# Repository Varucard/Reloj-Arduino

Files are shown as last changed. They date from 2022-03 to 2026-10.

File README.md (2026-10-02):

# Reloj Arduino



Reloj despertador casero hecho con Arduino. Muestra la hora, la fecha, la temperatura y la humedad ambiente, y tiene una alarma que se apaga **sacudiendo el reloj**.

## Funcionalidades

- Hora y fecha desde un módulo RTC DS1302, que mantiene la hora aunque se corte la alimentación.
- Temperatura y humedad con un sensor DHT11, actualizadas cada 6 segundos.
- Alarma con melodía en un buzzer, guardada en EEPROM, que se conserva al reiniciar.
- La alarma se apaga con 6 sacudidas (sensor de inclinación SW-520D), con el botón ALARM o sola a los 5 minutos.
- Ajuste de fecha, hora y alarma desde los botones, sin necesidad de reprogramar.
- Luz de fondo de la pantalla que se puede prender y apagar.

## Hardware

| Componente | Detalle |
|---|---|
| Placa | Arduino Uno o Arduino Pro Mini (ATmega328P) |
| Pantalla | LCD 16x2 con adaptador I2C (PCF8574, dirección `0x27`) |
| Reloj | Módulo RTC DS1302 |
| Sensor ambiente | DHT11 |
| Sensor de movimiento | SW-520D (inclinación) |
| Sonido | Buzzer pasivo |
| Entradas | 5 pulsadores |

### Conexiones

| Pin Arduino | Conectado a |
|---|---|
| A4 / A5 | LCD I2C (SDA / SCL) |
| 4 | Botón LOOK |
| 5 | DHT11 (datos) |
| 6 / 7 / 8 | DS1302 (CLK / DAT / RST) |
| 9 | Botón SET |
| 10 | Botón UP |
| 11 | Botón DOWN |
| 12 | Botón ALARM |
| 13 | Buzzer |
| A3 | SW-520D |

Los botones van entre el pin y GND; se usan las resistencias pull-up internas. Los esquemas completos están en [`hardware/esquemas`](hardware/esquemas) (PNG y archivos editables de [Fritzing](https://fritzing.org/)).

## Uso

| Botón | Funcionamiento normal | En modo ajuste |
|---|---|---|
| **SET** | Entra al modo ajuste | Pasa al siguiente campo; en el último, guarda |
| **UP** | — | Aumenta el valor |
| **DOWN** | Prende o apaga la luz de fondo | Disminuye el valor |
| **ALARM** | Arma o desarma la alarma; si está sonando, la silencia | — |
| **LOOK** | Muestra un segundo la hora de la alarma y su estado | — |

El modo ajuste recorre, en orden: hora → minutos → día → mes → año → hora de alarma → minutos de alarma. El RTC solo se reescribe si se modificó la fecha o la hora (los segundos se ponen en 00); si solo se cambia la alarma, la hora del reloj no se toca.

```
Pantalla principal   Info de alarma       Ajuste fecha/hora    Ajuste alarma
+----------------+   +----------------+   +----------------+   +----------------+
|HH:MM DD/MM/YYYY|   |HH:MM:SS| HH:MM |   |    >HH : MM    |   |SET  ALARM TIME |
|Temp:27c Hum:74%|   |DD/MM/YYYY| ON  |   | DD / MM / YYYY |   |    >HH : MM    |
+----------------+   +----------------+   +----------------+   +----------------+
```

## Compilación

### Librerías

| Librería | Uso | Instalación |
|---|---|---|
| [DHTlib](https://github.com/RobTillaart/DHTlib) | `dht.h` – sensor DHT11 | Gestor de librerías del IDE |
| [New LiquidCrystal](https://github.com/fmalpartida/New-LiquidCrystal) | `LCD.h`, `LiquidCrystal_I2C.h` – pantalla | Agregar el `.zip` desde GitHub |
| [virtuabotixRTC](https://github.com/chrisfryer78/ArduinoRTClibrary) | `virtuabotixRTC.h` – DS1302 | [`libraries/virtuabotixRTC.zip`](libraries) |

> **Importante:** New LiquidCrystal reemplaza a la librería `LiquidCrystal_I2C` de Frank de Brabander. Si tenés esa otra instalada, desinstalala o renombrala, porque si no el sketch no compila.

### Arduino IDE

1. Instalar las librerías (*Programa → Incluir librería → Añadir biblioteca .ZIP*).
2. Abrir `firmware/RelojArduino/RelojArduino.ino`.
3. Elegir la placa (Uno o Pro Mini) y subir.

### arduino-cli

```bash
arduino-cli core install arduino:avr
arduino-cli lib install DHTlib
arduino-cli config set library.enable_unsafe_install true
arduino-cli lib install --git-url https://github.com/fmalpartida/New-LiquidCrystal.git
arduino-cli lib install --zip-path libraries/virtuabotixRTC.zip

arduino-cli compile firmware/RelojArduino                               # Uno (por defecto)
arduino-cli compile -b arduino:avr:pro firmware/RelojArduino            # Pro Mini
arduino-cli upload -p /dev/ttyUSB0 firmware/RelojArduino
```

Cada push compila el firmware automáticamente para ambas placas con GitHub Actions.

## Estructura del repositorio

```
firmware/RelojArduino/   Sketch principal
hardware/esquemas/       Diagramas de conexión (PNG y Fritzing .fzz)
libraries/               Copias de las librerías usadas
docs/datasheets/         Hojas de datos de los componentes
docs/referencias/        Proyectos de Instructables en los que se basa este reloj
```

## Créditos

Basado en estos proyectos de Instructables, adaptados y extendidos:

- [Arduino Digital Clock With Alarm Function (custom PCB)](https://www.instructables.com/Arduino-Digital-Clock-With-Alarm-Function-custom-P/)
- [Arduino Digital Clock Thermometer (3D Printer Files)](https://www.instructables.com/Arduino-Digital-Clock-Thermometer-3D-Printer-Files/)

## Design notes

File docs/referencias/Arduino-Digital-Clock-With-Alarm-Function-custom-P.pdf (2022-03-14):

instructables

## Arduino Digital Clock With Alarm Function (custom PCB)

by Ardumotive_com

In this DIY guide I will show you how to make your own digital clock this alarm function.

In this project I decided to make my own PCB that is based on Arduino UNO microcontroller -Atmega328p.

Bellow you will find the electronic schematic with PCB layout so you can easily produce it.

By pressing the buttons you will be able to set time/date/alarm and alarm state (on/off).

The alarm can be turned off by pressing the alarm button or by shacking the box.

Updates and more can be found here: http://www.ardumotive.com/arduino-digital-clock-with-alarm-functionen.html

Let's get started.

https://www.youtube.com/embed/auJJn6xp2Go

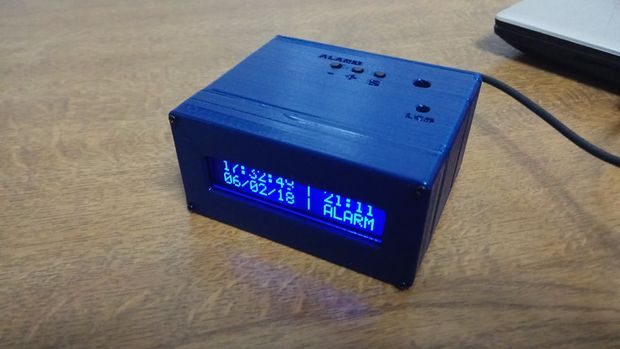
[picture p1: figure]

Arduino Digital Clock With Alarm Function (custom PCB): Page 1

### Step 1: What You Will Need - Hardware

For this project you will need:

Our custom PCB circuit
High Contrast 16x2 Character LCD (Raystar RC1602B-LLG-JWVE) Atmega328 (with Arduino UNO bootloader)
DS1307 Real Time Clock
Tilt Sensor
28 dip socket & 8 dip socket
16 MHz crystal oscillator
32.768 MHz crystal oscillator 2x22 pF capacitors
3x10 kOhm resistor
Trimmer 20kOhm
Buzzer
Coin Cell Battery Holder
screw terminal 2P 2.54mm
Pin Header 1x5 Female 2.54mm Mini Push Button Switch - Tall

You will also need a TTL to USB module or an Arduino UNO board for the programming procedure.

For power you will need a 5V-1A power adapter or you can use a usb cable as I did.

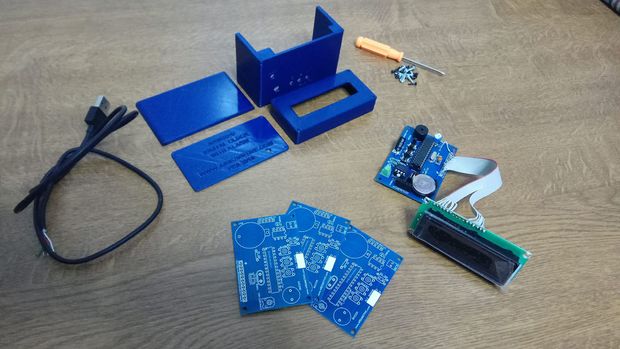
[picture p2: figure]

### Step 2: The Circuit at EasyEDA, the Free Online Circuit Design Platform

Enter here to see and make any changes to the above circuit.

Arduino Digital Clock With Alarm Function (custom PCB): Page 2

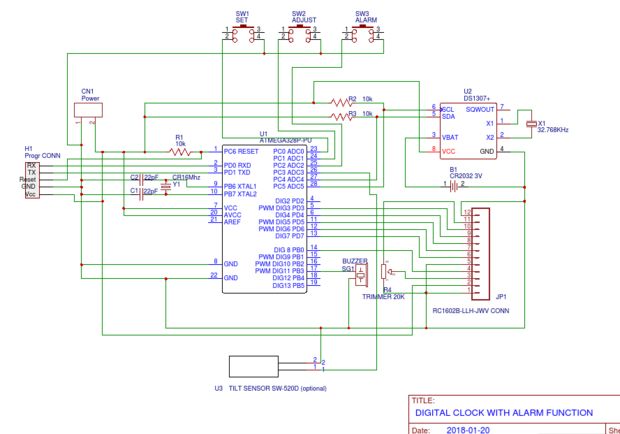
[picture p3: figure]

http://www.instructables…

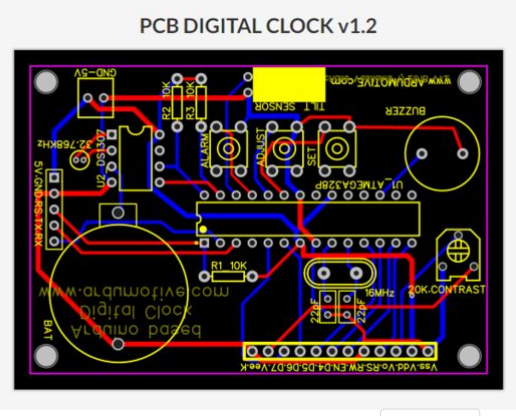
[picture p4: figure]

Download

### Step 3: The Code

How to program it:

Connect your circuit with TTL to USB module with 5 cables to the programming header.

The pins RX and TX must be cross-connected.

NOTE: If you are using the Arduino UNO board make sure to remove the ATmega328 IC from it first and connect the headers RX to RX and TX to TX pins of the board. The RS pin must be connected to Arduino UNO reset pin.

Download the code from here and open it with Arduino IDE. Inside you will also find the library file.

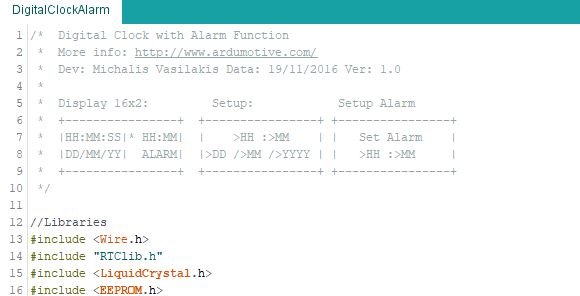
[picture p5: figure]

http://www.instructables…

Download

Arduino Digital Clock With Alarm Function (custom PCB): Page 3

### Step 4: JLCPCB - Make Your Own Circuit Boad From 2$!

Enter here to produce your PCB board!

Use JLCPCB for $2 PCB Fabrication & 2-day Build Time, the quality is really good, check the below photo of our pcb board.

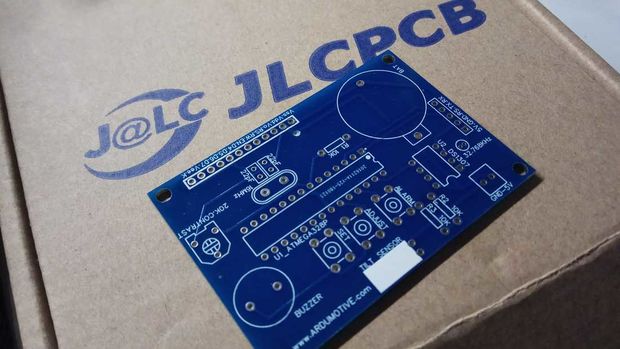
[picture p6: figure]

### Step 5: 3D Parts

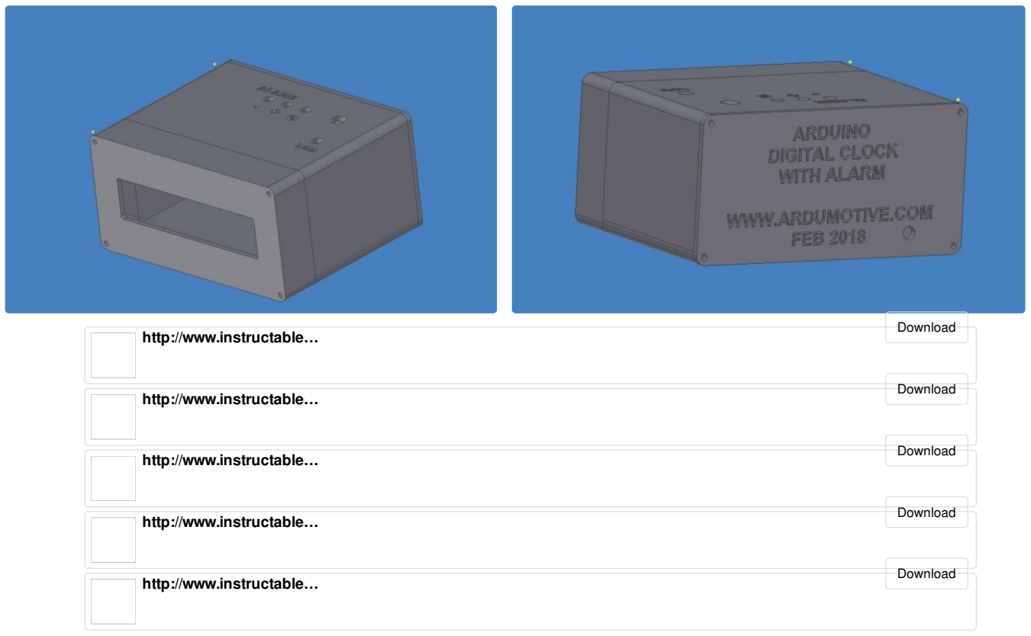
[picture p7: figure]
http://www.instructables…; Download

Arduino Digital Clock With Alarm Function (custom PCB): Page 4

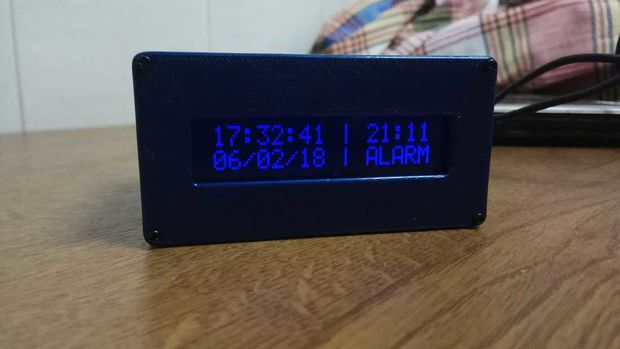
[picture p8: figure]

Thank you very much for your comment! I really appreciate it!
* Part list updated
* About video, I will try to make a better one next time and I will follow your advice
* I understand what you are telling me about easyeda and I will agree with you
* About JLCPCB, I will disagree with you, the quality of my PCBs is very good
* About connections, PCB layout has labels for all connection parts, plus CN1 (power).

With regard to the PCB, you and I are actually in full agreement. Your PCB quality is good because your layout work and attention to design rules were very good. I think you did a good job on the PCB.

I can't say the same for nearly every other project I've seen from JLCPCB.

But yours are good!

I'm not a fan of EasyEDA or JLCPCB because many of the projects that end up on Instructables are junk. But I think this project is a bit better than it's peers. I like this one and think it looks totally cool. The author has included information on almost everything you would need to make the project including 3D print files for the case. So you don't really need to buy the PCB from JLCPCB. You could even wire this up on perfboard if you wanted to spend the time on it.

For some reason EasyEDA doesn't produce clean schematics. Most of the projects using it have lines running through text or components, text too close, component outlines too small for the text within them... stuff like that. The schematic for this project has some of those, but it appears the author did spend a good bit of time getting the drawing to look right. I'm not sure if you can download the schematic from the EasyEDA site referenced by the author and use it with a better schematic editor, but at least there's a decent schematic to go with this project.

I have the same issue with EasyEDA PCB layouts. Most projects featuring it look terrible. Wrong part outlines, extremely poor layout, silkscreen text run over pads, silkscreen text run over mounting holes, and worse... silkscreen text under component bodies. But the author of this project has taken the time to do a decent layout. All parts fit and are in their proper place. One of the few I've seen from JLCPCB that are even close to usable.

The author includes a parts list, but I would have liked more complete specifications or a link on the

### Step 6: Well Done!

I hope you liked this, let me know in the comments!!!

Arduino Digital Clock With Alarm Function (custom PCB): Page 5

Instructables site that shows where they can be ordered from. This is done in the authors
EasyEDA site, so if you need more information on the parts you'll need to visit the EasyEDA site. It just would have been nice to see that on the Instructables site.

A couple of omissions to be aware of:

The push button switches aren't included in the parts list. You can see them in the picture but for the case to go together properly, the exact switch the author used needs to be ordered.

The LCD display isn't specified. This might be one of those Arduino parts that everybody has and everybody knows what it is, but I think it would be better to include a description and link to the display used.

The USB cable shown isn't specified. It would be great if a part number or link were provided for this.

From an assembly standpoint:

It's not clear how the LCD is wired into the main PCB. A little more information on that would be helpful for those who haven't done it before. Including this on a separate schematic page or illustration diagram would have been great.

It's not clear what the USB cable with the bare leads is for. A little more information on that would be helpful. I'm assuming that cable is used to power the clock with 5V via connector CN1. But it's not clear and available documentation is silent.

There is mention that a TTL to USB module is needed but that's not shown or described. A little more information on that module and how to connect it would be helpful for those who haven't programmed an Atmega chip in a dedicated PCB before. The less additional research the reader has to do, the more time they can spend just building the project.

The video is nice to have, but half of it is the usual advertisement for JLCPCB. The author could have used that time to include additional information on how to build and program the project. But least every single step in this Instructable doesn't come with the usual appeal to "Buy the PCB! Buy the PCB!" I hate that.

Minus a few missing parts, this is an project that can be made using the information the author has provided. It looks cool and you can build it however you want.

Arduino Digital Clock With Alarm Function (custom PCB): Page 6

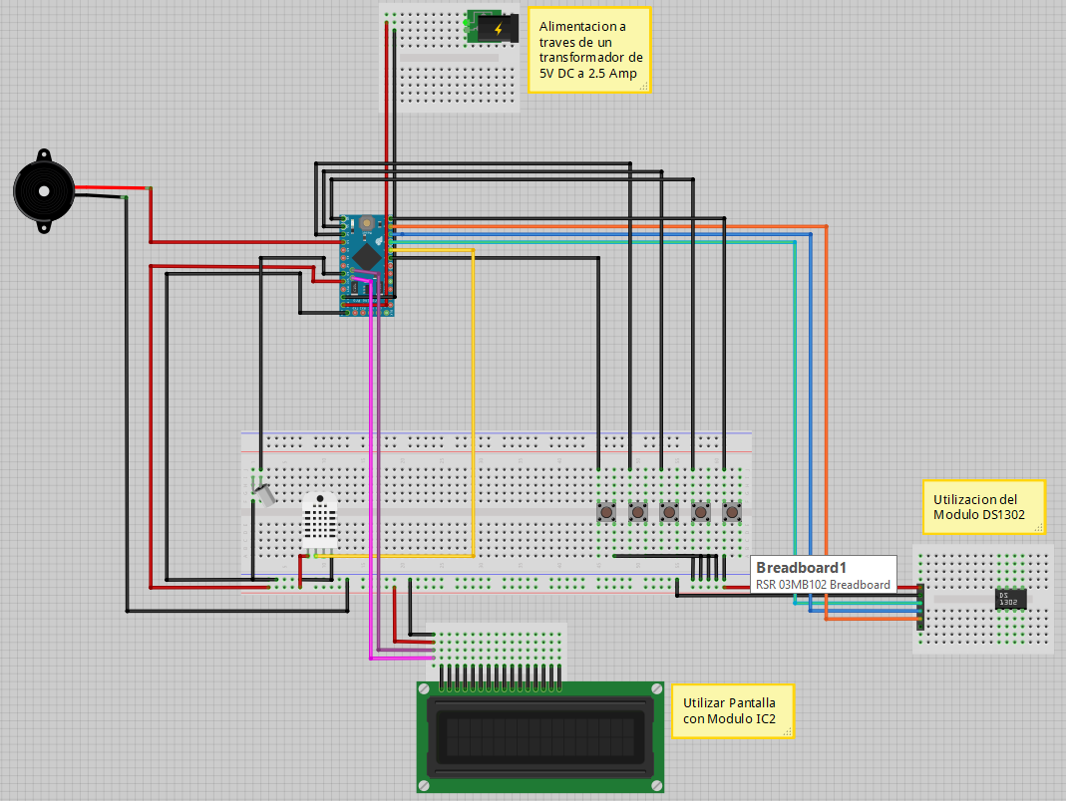
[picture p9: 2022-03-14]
hardware/esquemas/reloj-arduino-pro-mini.png

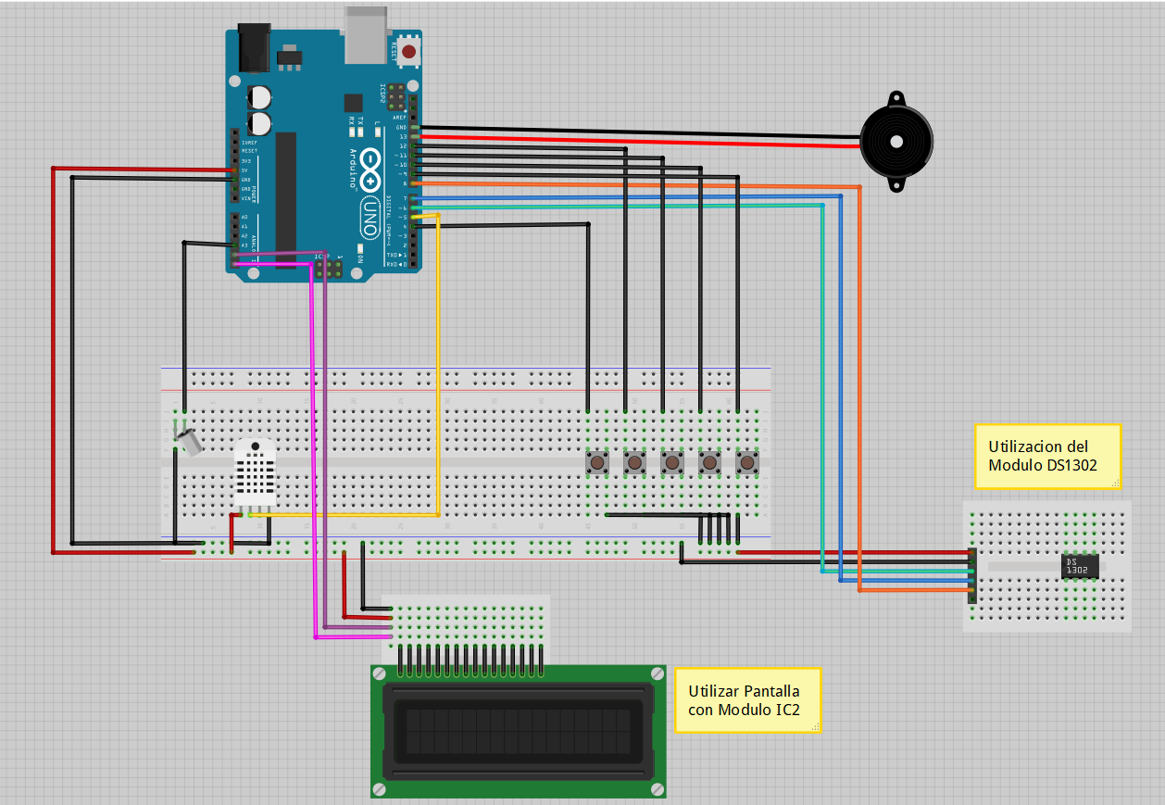
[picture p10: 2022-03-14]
hardware/esquemas/reloj-arduino-uno.png

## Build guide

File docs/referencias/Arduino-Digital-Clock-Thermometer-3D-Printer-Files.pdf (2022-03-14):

http://www.instructables.com/id/Arduino-Digital-Clock-Thermometer-3D-Printer-Files/technology (http://www.instructables.com/tag/type-id/category-technology/) workshop (http://www.instructables.com/tag/type-id/category-workshop/) craft (http://www.instructables.com/tag/type-id/category-craft/) home (http://www.instructables.com/tag/type-id/category-home/) food (http://www.instructables.com/tag/type-id/category-food/) play (http://www.instructables.com/tag/type-id/category-play/) outside (http://www.instructables.com/tag/type-id/category-outside/) costumes (http://www.instructables.com/tag/type-id/category-costumes/)

# Arduino Digital Clock & Thermometer (+3D Printer files)

by Ardumotive_com (http://www.instructables.com/member/Ardumotive_com/?utm_source=pdf&utm_campaign=title) on December 4, 2016

Table of Contents

## Intro: Arduino Digital Clock & Thermometer (+3D Printer files)

In this "how to" guide i will show you how to make your own digital clock-thermometer with the Arduino Pro mini board. (yes, you can use any other Arduino boad) .

You will be able to change the current date and time with Set-Up-Down buttons. The "down" button can also be used to turn on/off the screen backlight. The time and date values are stored in memory of the RTC.

The Temperature and humidity values updated every 5 seconds. We will use the DHT-21 sensor, but you can also use the DHT-11 and DHT-22 versions (you will need to make some changes in the code below).

Visit this page for further updates: http://www.ardumotive.com/digitalclockther-en.html

Watch the presentation video below.

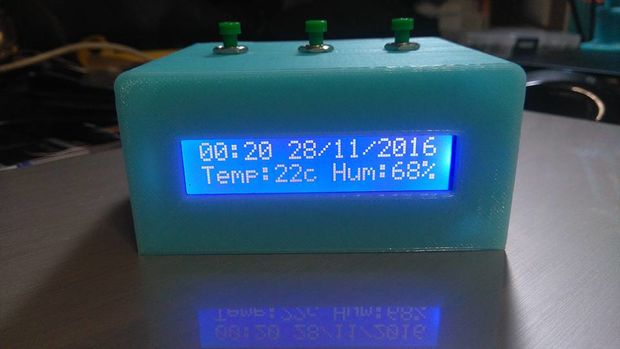
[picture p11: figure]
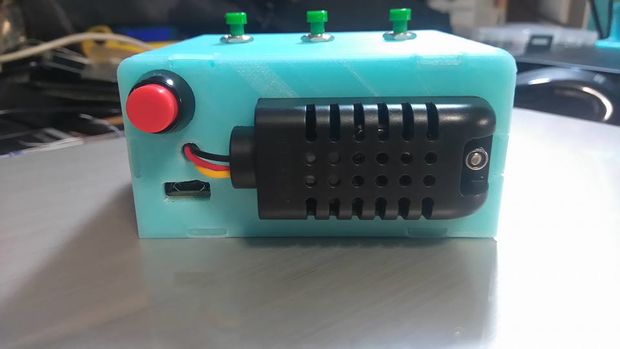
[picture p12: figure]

## Step 1: What you will need - Hardware

For this project you will need:

Arduino Pro Mini (5v version)
I2C LCD 16x2
DHT-21
RTC DS1307 (module with cell battery)
3 push buttons
1 on/off button

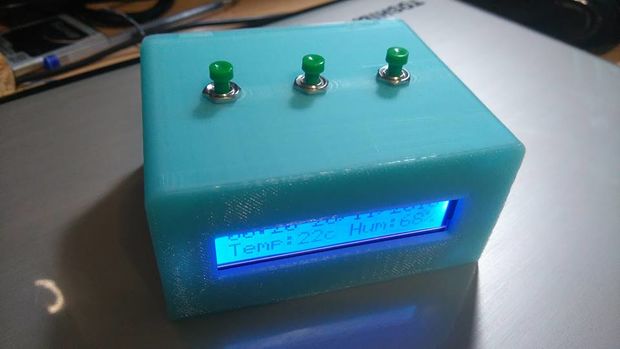
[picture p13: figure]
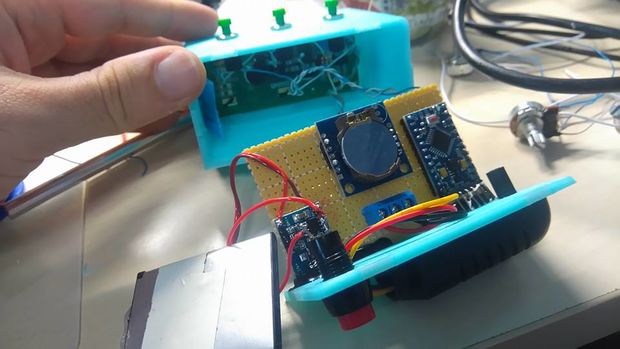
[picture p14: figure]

If you want you can use a rechargeable battery and a charging circuit as I did. (I used an old 950mAh mobile phone battery)

Or you can simply use one DC jack and one 5V power adapter to power it up!

## Step 2: The circuit

The circuit is really simple.

The i2c lcd and RTC module must be connected to the Arduino SDA and SCL pins. If you are using the Arduino uno or Arduino Pro Mini (or another board based in atMega328p micro controller), use the I2C interface at A4 (SDA) and A5(SCL) pins.

I2C LCD 16x2:
Vcc to power source (max 5V!)
GND to GNDSDA to pin A4
SCL to pin A5

RTC DS1307 module:
Vcc to power source (max 5V!) GND to GND

SDA to pin A4
SCL to pin A5

DHT-21:
Red cable to power source (max 5V!) Black cable to GND
Yellow cable to pin 5

Push buttons:

Set button to pin 8
Up button to pin 9
Down button to pin 10
The second pin of all buttons must be connected to ground (GND)

## Step 3: The code

Download the code from here and open it with Arduino IDE. Inside you will also find all necessary libraries.

If have any difficulties with the i2c LCD complete this tutorial. (http://www.ardumotive.com/i2clcden.html)

File Downloads

Clock_and_Thermometer_I2CLCD_DHT21.zip (http://www.instructables.comhttps://cdn.instructables.com/ORIG/F0Z/46G8/IW6PQNXL/F0Z46G8IW6PQNXL.zip) (6 MB)
[NOTE: When saving, if you see .tmp as the file ext, rename it to 'Clock_and_Thermometer_I2CLCD_DHT21.zip'] (http://www.instructables.comhttps://cdn.instructables.com/ORIG/F0Z/46G8/IW6PQNXL/F0Z46G8IW6PQNXL.zip)

## Step 4: 3D printing files

Here you will find the ipl and stl files of our box. You are free to make any changes you want. I made the 3d sketches with Autodesk Inventor 2017. This is my second 3d sketch, don't expect to be perfect :P

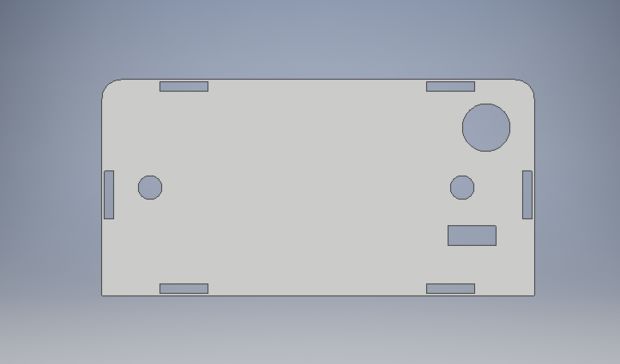
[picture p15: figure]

File Downloads

3DPrintedBox.zip (http://www.instructables.comhttps://cdn.instructables.com/ORIG/F3O/ZBS5/IW6PQOO1/F3OZBS5IW6PQOO1.zip) (358 KB)

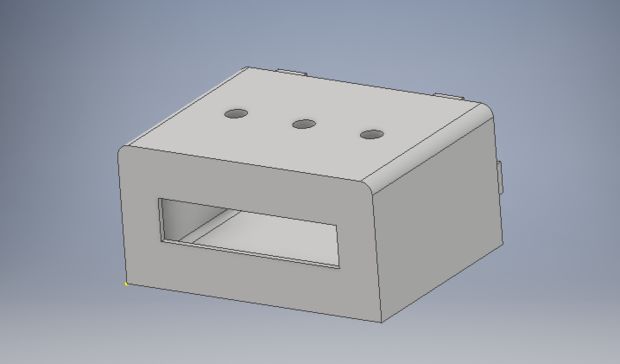
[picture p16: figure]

[NOTE: When saving, if you see .tmp as the file ext, rename it to '3DPrintedBox.zip'] (http://www.instructables.comhttps://cdn.instructables.com/ORIG/F3O/ZBS5/IW6PQOO1/F3OZBS5IW6PQOO1.zip)

## Step 5: Well done!

Great news! You have successfully complete this guide and now you have your own Arduino digital clock/thermometer!

I hope you liked this, let me know in the comments!

## Related Instructables

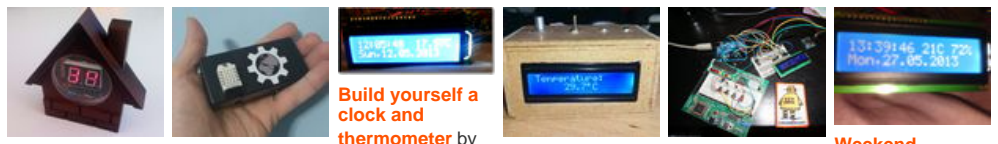
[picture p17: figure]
Build yourself a clock and

Seven Segment
Display
Thermometer -
Arduino Based (http://www.instructables.com/id/Seven-Segment-Display-Thermometer-Arduino-Based/)
by
Ardumotive_com (http://www.instructables.com/member/Ardumotive_com/?utm_source=pdf&utm_campaign=related)

Arduino IOT:
Temperature
and Humidity (http://www.instructables.com/id/Arduino-IOT-Temperature-and-Humidity-With-ESP8266-/) (
with ESP8266
WiFi) (http://www.instructables.com/id/Arduino-IOT-Temperature-and-Humidity-With-ESP8266-/) by
Ardumotive_com (http://www.instructables.com/member/Ardumotive_com/?utm_source=pdf&utm_campaign=related)

thermometer (http://www.instructables.com/id/Build-yourself-a-clock-and-thermometer/) by
arick (http://www.instructables.com/member/arick/?utm_source=pdf&utm_campaign=related) | Arduino Digital
| Thermometer
| (with DS18B20) (http://www.instructables.com/id/Arduino-Digital-Thermometer-with-DS18B20/)
| by
| Ardumotive_com (http://www.instructables.com/member/Ardumotive_com/?utm_source=pdf&utm_campaign=related)

Arduino
Powered 3-zone
thermostat (http://www.instructables.com/id/Arduino-Powered-3-zone-thermostat/) by
hbomb9000 (http://www.instructables.com/member/hbomb9000/?utm_source=pdf&utm_campaign=related)

Weekend
project clock
date
thermometer
and humidity
with Arduino
mega (http://www.instructables.com/id/Weekend-project-clock-date-thermometer-and-humidit/) by arick (http://www.instructables.com/member/arick/?utm_source=pdf&utm_campaign=related)

Advertisements

## Comments

2 comments | Add Comment (http://www.instructables.com/id/Arduino-Digital-Clock-Thermometer-3D-Printer-Files/)
Iqbal Samin (http://www.instructables.com/member/Iqbal+Samin/?utm_source=pdf&utm_campaign=comments) says: | Dec 5, 2016. 12:26 AM REPLY (http://www.instructables.com/id/Arduino-Digital-Clock-Thermometer-3D-Printer-Files/)
Very nice! How about adding alarm functions to it?
Ardumotive_com (http://www.instructables.com/member/Ardumotive_com/?utm_source=pdf&utm_campaign=comments) says: | Dec 5, 2016. 1:32 AM REPLY (http://www.instructables.com/id/Arduino-Digital-Clock-Thermometer-3D-Printer-Files/)
I will make an update, I will add a buzzer and some lines of code.

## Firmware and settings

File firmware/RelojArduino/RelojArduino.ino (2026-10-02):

/*
 * Reloj Arduino
 * Reloj con termómetro, higrómetro y alarma que se apaga por movimiento.
 *
 * Pantalla principal   Info alarma (LOOK)   Entrada a ajustes    Ajuste fecha/hora    Ajuste alarma
 * +----------------+   +----------------+   +----------------+   +----------------+   +----------------+
 * |HH:MM DD/MM/YYYY|   |HH:MM:SS| HH:MM |   |------SET------ |   |    >HH :>MM    |   |SET  ALARM TIME |
 * |Temp:27c Hum:74%|   |DD/MM/YYYY| ON  |   |-TIME and DATE- |   |>DD />MM />YYYY |   |    >HH :>MM    |
 * +----------------+   +----------------+   +----------------+   +----------------+   +----------------+
 *
 * Botones (a GND, con pull-up interno):
 *   SET   -> recorre los pasos de ajuste: hora, minutos, día, mes, año,
 *            hora de alarma, minutos de alarma; la última pulsación guarda.
 *   UP    -> incrementa el valor en ajuste.
 *   DOWN  -> decrementa el valor en ajuste / prende-apaga la luz de fondo.
 *   ALARM -> arma o desarma la alarma; si está sonando, la silencia.
 *   LOOK  -> muestra un segundo la pantalla de información de la alarma.
 */

#include <Wire.h>
#include <LCD.h>                // New LiquidCrystal (fmalpartida)
#include <LiquidCrystal_I2C.h>  // New LiquidCrystal (fmalpartida)
#include <dht.h>                // DHTlib (Rob Tillaart)
#include <virtuabotixRTC.h>     // Módulo RTC DS1302
#include <EEPROM.h>

// --- Pines ---
const uint8_t PIN_BTN_LOOK  = 4;
const uint8_t PIN_DHT11     = 5;
const uint8_t PIN_RTC_SCLK  = 6;
const uint8_t PIN_RTC_IO    = 7;
const uint8_t PIN_RTC_CE    = 8;
const uint8_t PIN_BTN_SET   = 9;
const uint8_t PIN_BTN_UP    = 10;
const uint8_t PIN_BTN_DOWN  = 11;
const uint8_t PIN_BTN_ALARM = 12;
const uint8_t PIN_BUZZER    = 13;
const uint8_t PIN_SHAKE     = A3;  // Sensor de inclinación SW-520D

// --- Configuración ---
const uint8_t       LCD_I2C_ADDR          = 0x27;
const unsigned long DHT_READ_INTERVAL_MS  = 6000;             // El DHT11 necesita >= 1 s entre lecturas
const unsigned long MELODY_STEP_MS        = 300;              // Tiempo entre notas de la alarma
const unsigned long ALARM_MAX_RING_MS     = 5UL * 60 * 1000;  // La alarma se apaga sola a los 5 minutos
const int           SHAKE_THRESHOLD       = 200;              // Lectura analógica que cuenta como movimiento
const uint8_t       SHAKES_TO_STOP        = 6;                // Movimientos necesarios para apagar la alarma
const int           MIN_YEAR              = 2000;             // El DS1302 solo guarda años 2000-2099
const int           MAX_YEAR              = 2099;
const int           MELODY[]              = {600, 800, 1000, 1200};
const uint8_t       MELODY_LEN            = sizeof(MELODY) / sizeof(MELODY[0]);

// Direcciones de EEPROM donde se guarda la hora de la alarma
const int EEPROM_ALARM_HOUR   = 0;
const int EEPROM_ALARM_MINUTE = 1;

// Pasos del modo ajuste (0 = funcionamiento normal)
enum SetupStep {
  STEP_NONE = 0,
  STEP_HOUR,
  STEP_MINUTE,
  STEP_DAY,
  STEP_MONTH,
  STEP_YEAR,
  STEP_ALARM_HOUR,
  STEP_ALARM_MINUTE
};

// LCD por I2C: dirección, En, Rw, Rs, D4, D5, D6, D7, luz de fondo, polaridad
LiquidCrystal_I2C lcd(LCD_I2C_ADDR, 2, 1, 0, 4, 5, 6, 7, 3, POSITIVE);
dht DHT;
virtuabotixRTC rtcModule(PIN_RTC_SCLK, PIN_RTC_IO, PIN_RTC_CE);  // La librería ya define un global "rtc"

// --- Estado ---
int day, month, year, hour, minute, second;
int temperature = 0, humidity = 0;
int alarmHour, alarmMinute;

uint8_t setupStep = STEP_NONE;
bool timeEdited   = false;  // Solo se escribe el RTC si el usuario cambió fecha u hora

bool backlightOn   = true;
bool alarmArmed    = false;
bool alarmRinging  = false;
bool alarmFired    = false;  // Evita que la alarma vuelva a sonar dentro del mismo minuto
unsigned long alarmStartMs  = 0;
unsigned long lastNoteMs    = 0;
uint8_t       melodyIndex   = 0;
uint8_t       shakeCount    = 0;
bool          lastShakeHigh = false;

unsigned long lastDhtReadMs = 0;

// Lectura de los botones en la vuelta actual del loop (LOW = presionado)
bool btnSet, btnUp, btnDown, btnAlarm, btnLook;

void setup() {
  // Para poner en hora un RTC nuevo se puede usar el menú SET, o descomentar
  // esta línea una sola vez: (segundos, minutos, hora, díaSemana 1-7, día, mes, año)
  // rtcModule.setDS1302Time(0, 5, 22, 3, 8, 3, 2022);

  pinMode(PIN_BTN_SET, INPUT_PULLUP);
  pinMode(PIN_BTN_UP, INPUT_PULLUP);
  pinMode(PIN_BTN_DOWN, INPUT_PULLUP);
  pinMode(PIN_BTN_LOOK, INPUT_PULLUP);
  pinMode(PIN_BTN_ALARM, INPUT_PULLUP);
  pinMode(PIN_BUZZER, OUTPUT);

  // Una EEPROM sin usar devuelve 255, por eso se valida
  alarmHour   = EEPROM.read(EEPROM_ALARM_HOUR);
  alarmMinute = EEPROM.read(EEPROM_ALARM_MINUTE);
  if (alarmHour > 23)   alarmHour = 0;
  if (alarmMinute > 59) alarmMinute = 0;

  lcd.begin(16, 2);
  lcd.backlight();
  lcd.clear();

  readTempHum();
}

void loop() {
  readButtons();

  if (millis() - lastDhtReadMs >= DHT_READ_INTERVAL_MS) {
    readTempHum();
  }

  if (setupStep == STEP_NONE) {
    readRtc();
    printMainScreen();
    updateAlarm();
  } else {
    handleSetup();
  }
}

// ---------------------------------------------------------------------------
// Botones
// ---------------------------------------------------------------------------

void readButtons() {
  btnSet   = digitalRead(PIN_BTN_SET) == LOW;
  btnUp    = digitalRead(PIN_BTN_UP) == LOW;
  btnDown  = digitalRead(PIN_BTN_DOWN) == LOW;
  btnAlarm = digitalRead(PIN_BTN_ALARM) == LOW;
  btnLook  = digitalRead(PIN_BTN_LOOK) == LOW;

  if (btnAlarm) {
    if (alarmRinging) {
      stopRinging();  // Silencia sin desarmar: mañana vuelve a sonar
    } else {
      alarmArmed = !alarmArmed;
    }
    delay(500);
  }

  if (btnLook) {
    lcd.clear();
    printAlarmInfoScreen();
    delay(1000);
    lcd.clear();
  }

  if (btnDown && setupStep == STEP_NONE) {
    backlightOn = !backlightOn;
    if (backlightOn) lcd.backlight(); else lcd.noBacklight();
    delay(500);
  }

  if (btnSet) {
    if (setupStep < STEP_ALARM_MINUTE) {
      if (setupStep == STEP_NONE) {
        stopRinging();
        timeEdited = false;
        lcd.clear();
        lcd.setCursor(0, 0);
        lcd.print("------SET------");
        lcd.setCursor(0, 1);
        lcd.print("-TIME and DATE-");
        delay(2000);
        lcd.clear();
      }
      setupStep++;
    } else {
      saveSettings();
      setupStep = STEP_NONE;
    }
    delay(500);
  }
}

// ---------------------------------------------------------------------------
// Sensores
// ---------------------------------------------------------------------------

void readTempHum() {
  lastDhtReadMs = millis();
  // Si la lectura falla se conservan los últimos valores válidos
  if (DHT.read11(PIN_DHT11) == DHTLIB_OK) {
    humidity    = DHT.humidity;
    temperature = DHT.temperature;
  }
}

void readRtc() {
  rtcModule.updateTime();
  day    = rtcModule.dayofmonth;
  month  = rtcModule.month;
  year   = rtcModule.year;
  hour   = rtcModule.hours;
  minute = rtcModule.minutes;
  second = rtcModule.seconds;
}

// ---------------------------------------------------------------------------
// Pantallas
// ---------------------------------------------------------------------------

void printLine(uint8_t row, const char *text) {
  lcd.setCursor(0, row);
  lcd.print(text);
}

void printMainScreen() {
  char line[17];
  snprintf(line, sizeof(line), "%02d:%02d %02d/%02d/%04d", hour, minute, day, month, year);
  printLine(0, line);
  snprintf(line, sizeof(line), "Temp:%2dc Hum:%2d%%", temperature, humidity);
  printLine(1, line);
}

void printAlarmInfoScreen() {
  char line[17];
  snprintf(line, sizeof(line), "%02d:%02d:%02d| %02d:%02d", hour, minute, second, alarmHour, alarmMinute);
  printLine(0, line);
  snprintf(line, sizeof(line), "%02d/%02d/%04d| %-3s", day, month, year, alarmArmed ? "ON" : "OFF");
  printLine(1, line);
}

// Línea "    >HH :>MM    " con el cursor '>' delante del campo que se está editando
void printHourMinuteLine(uint8_t row, int h, int m, bool markHour, bool markMinute) {
  char line[17];
  snprintf(line, sizeof(line), "    %c%02d :%c%02d    ",
           markHour ? '>' : ' ', h, markMinute ? '>' : ' ', m);
  printLine(row, line);
}

void printSetupScreen() {
  if (setupStep <= STEP_YEAR) {
    char line[17];
    printHourMinuteLine(0, hour, minute, setupStep == STEP_HOUR, setupStep == STEP_MINUTE);
    snprintf(line, sizeof(line), "%c%02d /%c%02d /%c%04d ",
             setupStep == STEP_DAY ? '>' : ' ', day,
             setupStep == STEP_MONTH ? '>' : ' ', month,
             setupStep == STEP_YEAR ? '>' : ' ', year);
    printLine(1, line);
  } else {
    printLine(0, "SET  ALARM TIME ");
    printHourMinuteLine(1, alarmHour, alarmMinute,
                        setupStep == STEP_ALARM_HOUR, setupStep == STEP_ALARM_MINUTE);
  }
}

// ---------------------------------------------------------------------------
// Modo ajuste
// ---------------------------------------------------------------------------

// Suma delta a value dando la vuelta dentro de [minValue, maxValue]
int wrap(int value, int delta, int minValue, int maxValue) {
  value += delta;
  if (value > maxValue) return minValue;
  if (value < minValue) return maxValue;
  return value;
}

bool isLeapYear(int y) {
  return (y % 4 == 0 && y % 100 != 0) || y % 400 == 0;
}

int daysInMonth(int m, int y) {
  static const uint8_t DAYS[] = {31, 28, 31, 30, 31, 30, 31, 31, 30, 31, 30, 31};
  return (m == 2 && isLeapYear(y)) ? 29 : DAYS[m - 1];
}

// Día de la semana 1-7 (1 = domingo), algoritmo de Sakamoto
int dayOfWeek(int d, int m, int y) {
  static const uint8_t T[] = {0, 3, 2, 5, 0, 3, 5, 1, 4, 6, 2, 4};
  if (m < 3) y--;
  return (y + y / 4 - y / 100 + y / 400 + T[m - 1] + d) % 7 + 1;
}

void handleSetup() {
  int delta = (btnUp ? 1 : 0) - (btnDown ? 1 : 0);

  if (delta != 0) {
    switch (setupStep) {
      case STEP_HOUR:         hour        = wrap(hour, delta, 0, 23); break;
      case STEP_MINUTE:       minute      = wrap(minute, delta, 0, 59); break;
      case STEP_DAY:          day         = wrap(day, delta, 1, daysInMonth(month, year)); break;
      case STEP_MONTH:        month       = wrap(month, delta, 1, 12); break;
      case STEP_YEAR:         year        = wrap(year, delta, MIN_YEAR, MAX_YEAR); break;
      case STEP_ALARM_HOUR:   alarmHour   = wrap(alarmHour, delta, 0, 23); break;
      case STEP_ALARM_MINUTE: alarmMinute = wrap(alarmMinute, delta, 0, 59); break;
    }
    if (setupStep <= STEP_YEAR) {
      timeEdited = true;
      // Corrige días inválidos al cambiar mes o año (ej.: 31/04 -> 30/04)
      day = min(day, daysInMonth(month, year));
    }
    delay(350);
  }

  printSetupScreen();
}

void saveSettings() {
  lcd.clear();
  lcd.print("Saving....");

  // Si solo se ajustó la alarma no se toca el RTC: reescribirlo con la hora
  // leída al entrar al menú haría que el reloj se atrase.
  if (timeEdited) {
    rtcModule.setDS1302Time(0, minute, hour, dayOfWeek(day, month, year), day, month, year);
  }
  EEPROM.update(EEPROM_ALARM_HOUR, alarmHour);
  EEPROM.update(EEPROM_ALARM_MINUTE, alarmMinute);

  delay(2000);
  lcd.clear();
}

// ---------------------------------------------------------------------------
// Alarma
// ---------------------------------------------------------------------------

void startRinging() {
  alarmRinging  = true;
  alarmStartMs  = millis();
  lastNoteMs    = 0;
  melodyIndex   = 0;
  shakeCount    = 0;
  lastShakeHigh = false;
}

void stopRinging() {
  alarmRinging = false;
  noTone(PIN_BUZZER);
}

void updateAlarm() {
  bool isAlarmMinute = hour == alarmHour && minute == alarmMinute;
  if (!isAlarmMinute) {
    alarmFired = false;
  } else if (alarmArmed && !alarmFired) {
    alarmFired = true;
    startRinging();
  }

  if (!alarmArmed && alarmRinging) {
    stopRinging();
  }
  if (!alarmRinging) {
    return;
  }

  // Se cuenta cada vez que el sensor pasa de reposo a movimiento
  bool shakeHigh = analogRead(PIN_SHAKE) > SHAKE_THRESHOLD;
  if (shakeHigh && !lastShakeHigh) {
    shakeCount++;
  }
  lastShakeHigh = shakeHigh;

  unsigned long now = millis();
  if (shakeCount >= SHAKES_TO_STOP || now - alarmStartMs >= ALARM_MAX_RING_MS) {
    stopRinging();
    return;
  }

  if (now - lastNoteMs >= MELODY_STEP_MS) {
    lastNoteMs = now;
    tone(PIN_BUZZER, MELODY[melodyIndex], 100);
    melodyIndex = (melodyIndex + 1) % MELODY_LEN;
  }
}

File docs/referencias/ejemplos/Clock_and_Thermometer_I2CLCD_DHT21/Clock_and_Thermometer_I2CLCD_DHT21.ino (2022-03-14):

/*  Clock - Thermometer with Arduino
 *  More info: http://www.ardumotive.com/
 *  Dev: Michalis Vasilakis Data: 19/11/2016 Ver: 1.0
 *  
 *  Display 16x2:         Setup:
 *  +----------------+  +----------------+
 *  |HH:MM DD/MM/YYYY|  |    >HH :>MM    |
 *  |Temp:27c Hum:74%|  |>DD />MM />YYYY |
 *  +----------------+  +----------------+
 */

//Libraries
#include <Wire.h>
#include <RTClib.h>
#include <LiquidCrystal_I2C.h>
#include <dht.h>

//Init libraries objects
RTC_DS1307 rtc;
LiquidCrystal_I2C lcd(0x3F, 2, 1, 0, 4, 5, 6, 7, 3, POSITIVE);  // Set the LCD I2C address, if it's not working try 0x27.
dht DHT;

//Constants
char daysOfTheWeek[7][12] = {"Sunday","Monday", "Tuesday", "Wednesday", "Thursday", "Friday", "Saturday"};
#define DHT21_PIN 5     // DHT 22  (AM2302) - what pin we're connected to
const long interval = 6000;  // Read data from DHT every 6 sec
const int btSet = 8;
const int btUp = 9;
const int btDown = 10;

//Variables
int DD,MM,YY,H,M,S,temp,hum, set_state, up_state, down_state;
int btnCount = 0;
unsigned long previousMillis = 0;
unsigned long currentMillis; 
String sDD;
String sMM;
String sYY;
String sH;
String sM;
String sS;
boolean backlightON = true;
boolean setupScreen = false;


void setup () {
  pinMode(btSet, INPUT_PULLUP);
  pinMode(btUp, INPUT_PULLUP);
  pinMode(btDown, INPUT_PULLUP);
  lcd.begin(16,2);   // iInit the LCD for 16 chars 2 lines
  lcd.backlight();   // Turn on the backligt (try lcd.noBacklight() to turn it off)
  lcd.clear();
}

void loop () {
  currentMillis = millis();
  readBtns();
  getTempHum();    
  getTimeDate();
  if (!setupScreen){
    lcdPrint();
  }
  else{
    lcdSetup();
  }
}
//Read buttons
void readBtns(){
  set_state = digitalRead(btSet);
  up_state = digitalRead(btUp);
  down_state = digitalRead(btDown);
  //Turn backlight on/off by pressing the down button
  if (down_state==LOW && btnCount==0){
    if (backlightON){
      lcd.noBacklight();
      backlightON = false;
    }
    else{
      lcd.backlight();
      backlightON = true;
    }
    delay(500);
  }
  if (set_state==LOW){
    if(btnCount<5){
      btnCount++;
      setupScreen = true;
        if(btnCount==1){
          lcd.clear();
          lcd.setCursor(0,0);
          lcd.print("------SET------");
          lcd.setCursor(0,1);
          lcd.print("-TIME and DATE-");
          delay(2000);
          lcd.clear();
        }
    }
    else{
      lcd.clear();
      rtc.adjust(DateTime(YY, MM, DD, H, M, 0));
      lcd.print("Saving....");
      delay(2000);
      lcd.clear();
      setupScreen = false;
      btnCount=0;
    }
    delay(500);
  }
}
//Read temperature and humidity every 6 seconds from DHT sensor
void getTempHum(){
  if (currentMillis - previousMillis >= interval) {
    int chk = DHT.read21(DHT21_PIN);
    previousMillis = currentMillis;    
    hum = DHT.humidity;
    temp= DHT.temperature;
  }
}
//Read time and date from rtc ic
void getTimeDate(){
  if (!setupScreen){
    DateTime now = rtc.now();
    DD = now.day();
    MM = now.month();
    YY = now.year();
    H = now.hour();
    M = now.minute();
    S = now.second();
  }
  //Make some fixes...
  if (DD<10){ sDD = '0' + String(DD); } else { sDD = DD; }
  if (MM<10){ sMM = '0' + String(MM); } else { sMM = MM; }
  sYY=YY;
  if (H<10){ sH = '0' + String(H); } else { sH = H; }
  if (M<10){ sM = '0' + String(M); } else { sM = M; }
  if (S<10){ sS = '0' + String(S); } else { sS = S; }
}
//Print values to the display
void lcdPrint(){
  lcd.setCursor(0,0); //First row
  lcd.print(sH);
  lcd.print(":");
  lcd.print(sM);
  lcd.print(" ");
  lcd.print(sDD);
  lcd.print("/");
  lcd.print(sMM);
  lcd.print("/");
  lcd.print(sYY);
  lcd.setCursor(0,1); //Second row
  lcd.print("Temp:");
  lcd.print(temp);
  lcd.print("c");
  lcd.setCursor(9,1); //10 cell of second row
  lcd.print("Hum:");
  lcd.print(hum);
  lcd.print("%");
}
//Setup screen
void lcdSetup(){
  if (btnCount==1){
    lcd.setCursor(4,0);
    lcd.print(">"); 
    if (up_state == LOW){
      if (H<23){
        H++;
      }
      else {
        H=0;
      }
      delay(500);
    }
    if (down_state == LOW){
      if (H>0){
        H--;
      }
      else {
        H=23;
      }
      delay(500);
    }
  }
  else if (btnCount==2){
    lcd.setCursor(4,0);
    lcd.print(" ");
    lcd.setCursor(9,0);
    lcd.print(">");
    if (up_state == LOW){
      if (M<59){
        M++;
      }
      else {
        M=0;
      }
      delay(500);
    }
    if (down_state == LOW){
      if (M>0){
        M--;
      }
      else {
        M=59;
      }
      delay(500);
    }
  }
  else if (btnCount==3){
    lcd.setCursor(9,0);
    lcd.print(" ");
    lcd.setCursor(0,1);
    lcd.print(">");
    if (up_state == LOW){
      if (DD<31){
        DD++;
      }
      else {
        DD=1;
      }
      delay(500);
    }
    if (down_state == LOW){
      if (DD>1){
        DD--;
      }
      else {
        DD=31;
      }
      delay(500);
    }
  }
  else if (btnCount==4){
    lcd.setCursor(0,1);
    lcd.print(" ");
    lcd.setCursor(5,1);
    lcd.print(">");
    if (up_state == LOW){
      if (MM<12){
        MM++;
      }
      else {
        MM=1;
      }
      delay(500);
    }
    if (down_state == LOW){
      if (MM>1){
        MM--;
      }
      else {
        MM=12;
      }
      delay(500);
    }
  }
  else if (btnCount==5){
    lcd.setCursor(5,1);
    lcd.print(" ");
    lcd.setCursor(10,1);
    lcd.print(">");
    if (up_state == LOW){
      if (YY<2999){
        YY++;
      }
      else {
        YY=2000;
      }
      delay(500);
    }
    if (down_state == LOW){
      if (YY>2000){
        YY--;
      }
      else {
        YY=2999;
      }
      delay(500);
    }
  }
  lcd.setCursor(5,0);
  lcd.print(sH);
  lcd.setCursor(8,0);
  lcd.print(":");
  lcd.setCursor(10,0);
  lcd.print(sM);
  lcd.setCursor(1,1);
  lcd.print(sDD);
  lcd.setCursor(4,1);
  lcd.print("/");
  lcd.setCursor(6,1);
  lcd.print(sMM);
  lcd.setCursor(9,1);
  lcd.print("/");
  lcd.setCursor(11,1);
  lcd.print(sYY);
}

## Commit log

2022-03-14 confirmar en main
    [Diagramar Arduino Pro Mini.fzz, Diagramar Arduino Uno.fzz]
2026-10-02 Reorganizar estructura del repositorio
    - firmware/: sketch principal (antes Codigo/Definitivo)
    - hardware/esquemas/: diagramas Fritzing y PNG
    - docs/: datasheets, referencias y ejemplos de terceros
    - libraries/: librerías usadas por el proyecto
    - Se eliminan versiones anteriores del sketch (quedan en el historial)
    [reloj-arduino-pro-mini.fzz, reloj-arduino-uno.fzz]
2026-10-02 Profesionalizar proyecto y corregir errores del firmware
    Firmware:
    - Corrige el atraso del reloj: al salir del menú SET se reescribía el RTC
    con la hora leída al entrar; ahora solo se escribe si se editó fecha/hora
    - Limita el año a 2000-2099 (rango del DS1302) y valida días por mes
    - Temporizador propio para la melodía (antes compartía previousMillis
    con el DHT11 y usaba un millis() fijo en 10000)
    - El botón ALARM silencia la alarma mientras suena, sin desarmarla
    - Apagado automático a los 5 minutos sin depender de AM + 5
    - Cuenta sacudidas por flanco y elimina Serial.print sin Serial.begin
    - Reemplaza String por snprintf (menos RAM y sin fragmentación)
    - Calcula el día de l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
    [RelojArduino.ino]
